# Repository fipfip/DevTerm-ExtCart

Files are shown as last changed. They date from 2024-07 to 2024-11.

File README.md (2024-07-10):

# DevTerm-ExtCart

An extension board for the DevTerm, with Commodore64-style 44pin cartridge.
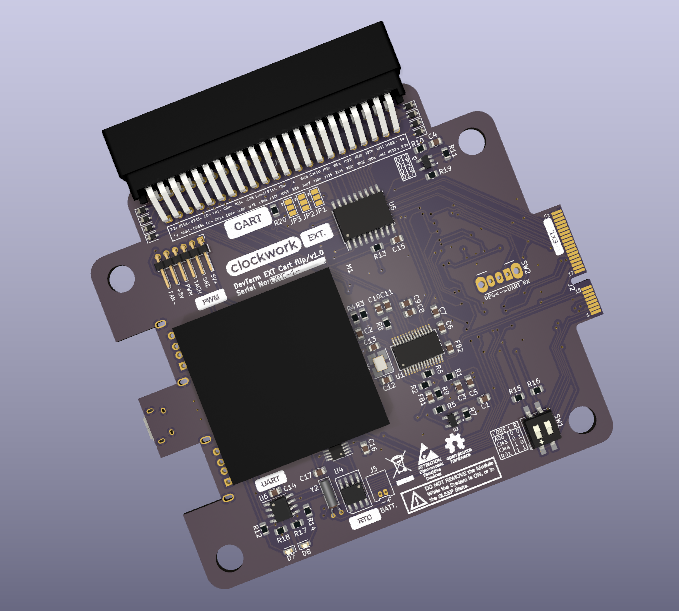
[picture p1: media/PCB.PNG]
PCB
 

## Design desiderata

Pin assignment:
- Maximum compatibility and function alignment.
- Strong coupling of differential pairs.
- Avoid damage.
All power pins are mirror safe.
Expansion port requirement:
- Pin 21 MUST connect to Pin 23.
- Pin 24 MUST be NC
ROUTE_EN disconnects all routed pins when cartridge is:
- Disconnected
- Inserted the wrong direction
Resource overview:
- 8x internal GPIOs
- 8x external GPIOs
- MIPI-CSI
- 3x USB 2.0
- 1x SPI
- 1x I2C
- 1x UART (Debug)
Resource management pins:
- IO36 for power management
- IO43 for cartridge detection

## PCB Physical specifications

- EXT board:
  - size: 89mm (height) x 101mm (width)
  - thickness: 1mm (source: https://www.ampltd.com/minipcie/)
- Carts:
  - size: 61mm (max height inside DevTerm) x 58.42mm (width)
  - thickness: 1.6mm (source: https://dirtypcbs.com/store/designer/details/12317/1036/cartridge-board-for-commodore-64)

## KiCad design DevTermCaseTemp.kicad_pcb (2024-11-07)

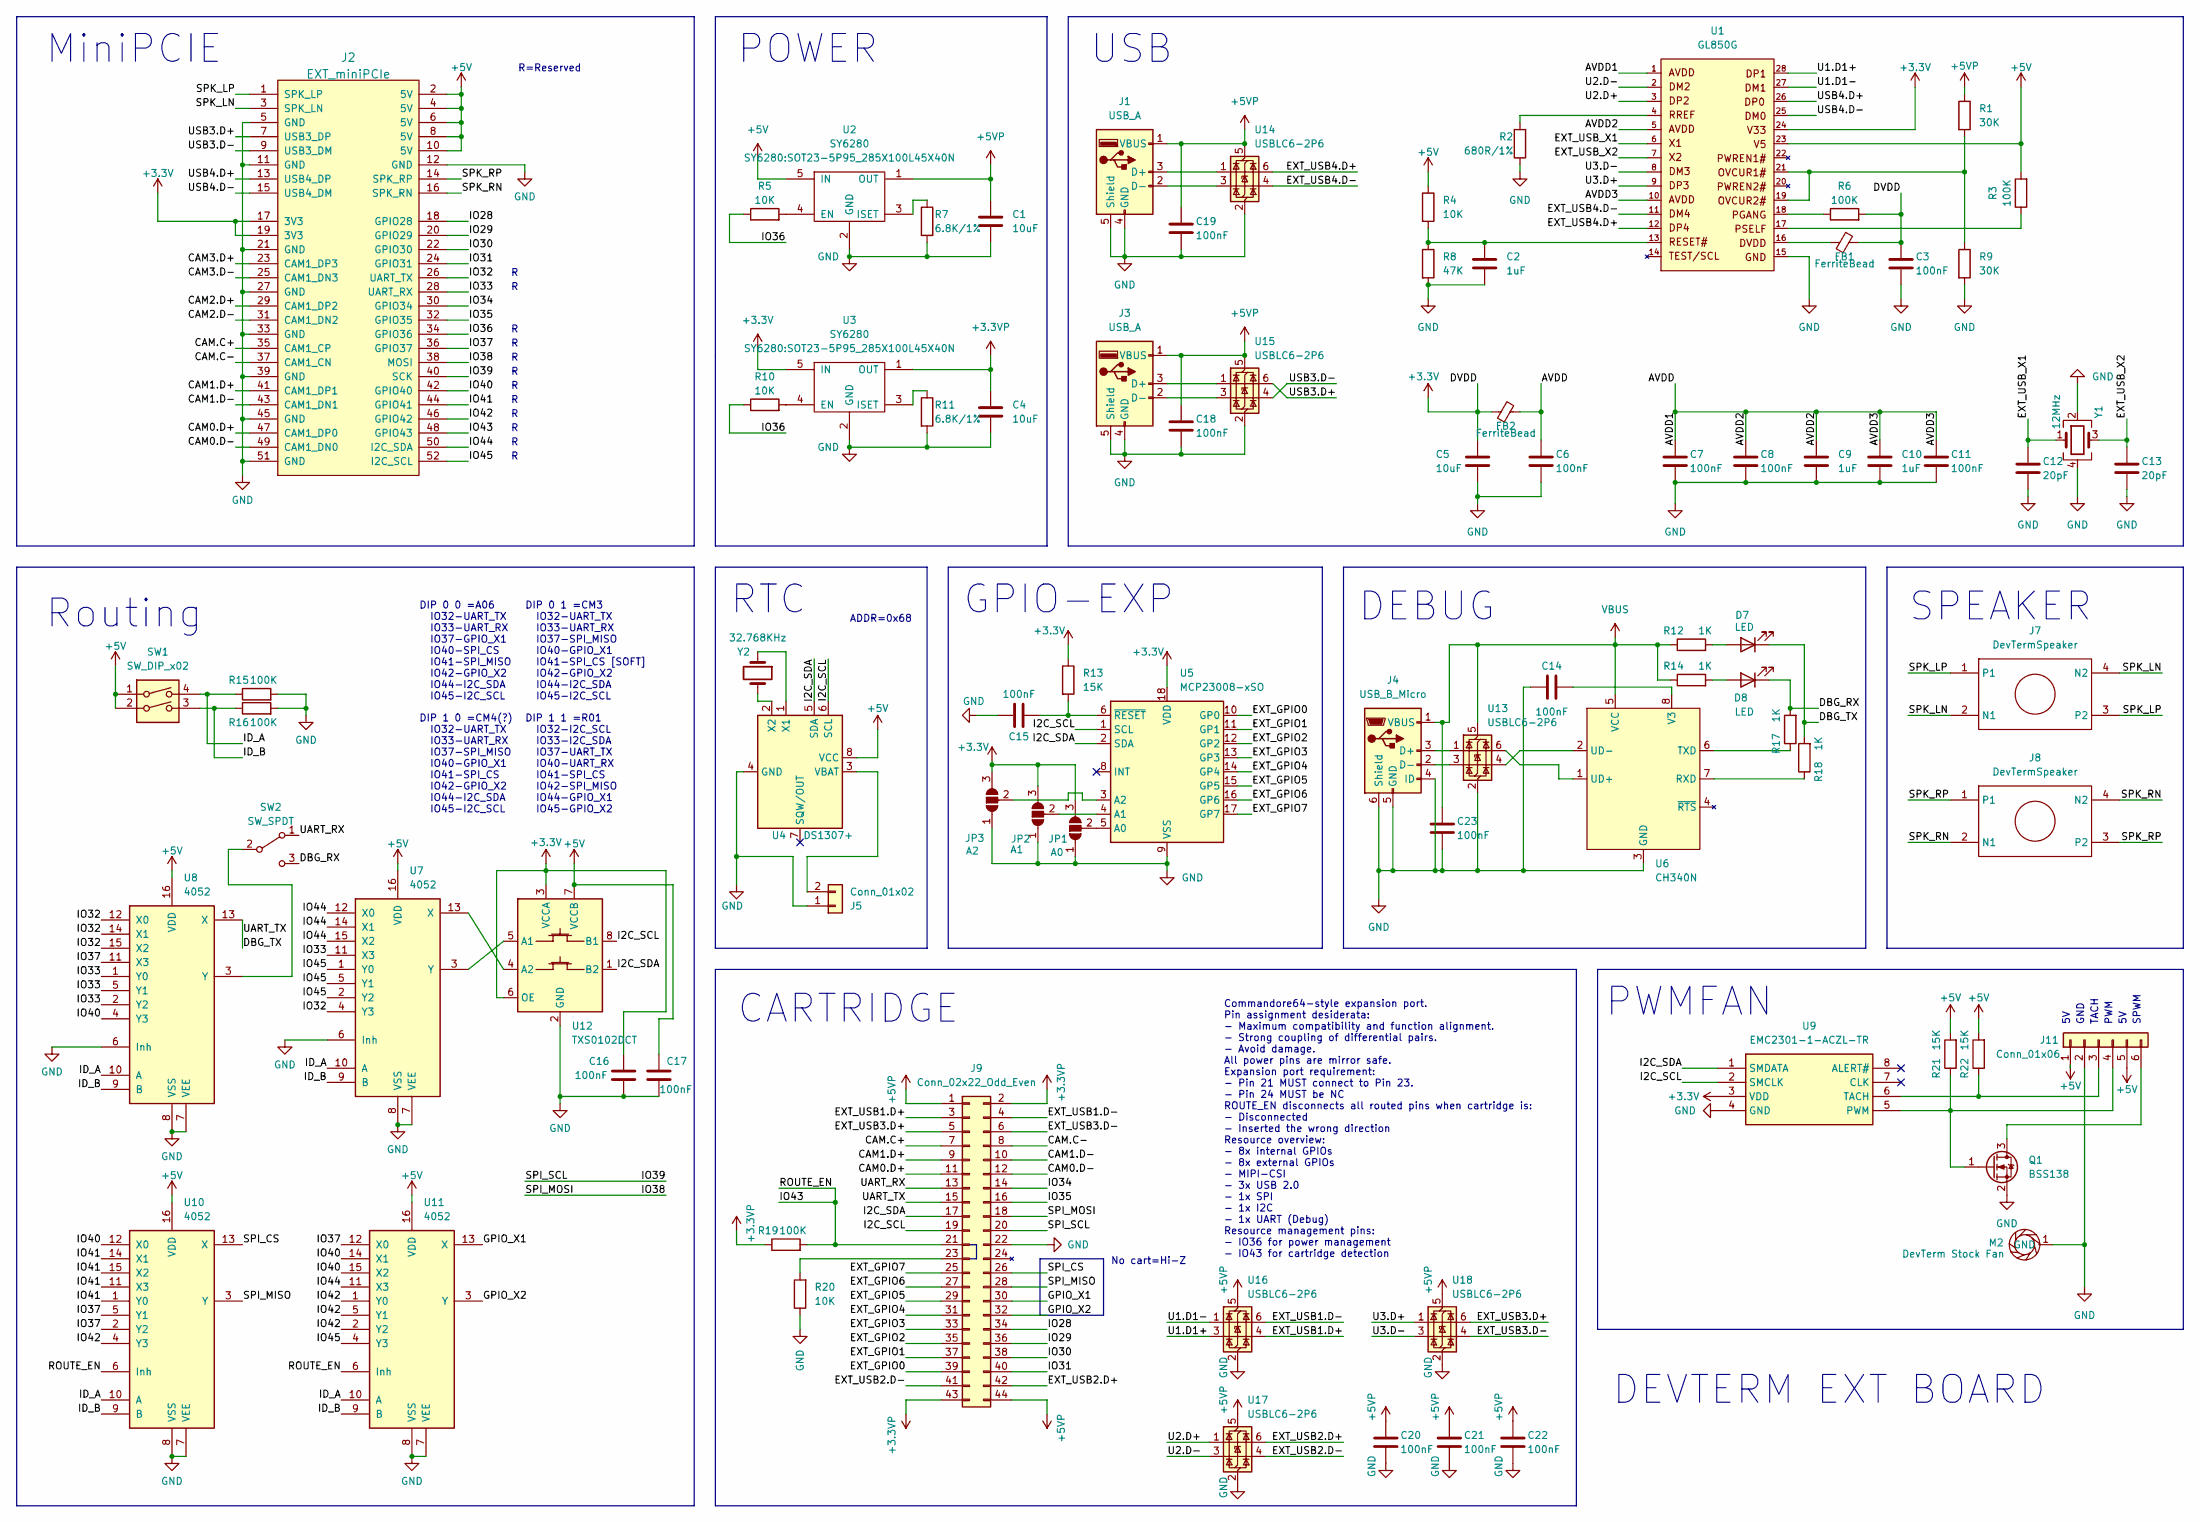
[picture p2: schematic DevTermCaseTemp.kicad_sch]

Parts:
C1, C4, C5: 10uF; C_0805_2012Metric
C2, C9, C10: 1uF; C_0805_2012Metric
C3, C6, C7, C8, C11, C14, C15, C16, C17, C18, C19, C20, C21, C22, C23: 100nF; C_0805_2012Metric
C12, C13: 20pF; C_0805_2012Metric
D7, D8: LED; LED_0603_1608Metric
FB1, FB2: FerriteBead; C_0805_2012Metric
J1, J3: USB_A; USB_A_PCBCUT
J2: EXT_miniPCIe; mini-PCIe
J4: USB_B_Micro; USB_Micro-B_Amphenol_10118194_Horizontal
J5: Conn_01x02; Molex_PicoBlade_53048-0210_1x02_P1.25mm_Horizontal
J7, J8: DevTermSpeaker; DevTerm-Speaker
J9: Conn_02x22_Odd_Even; C64-Cart-Socket-Horizontal
J11: Conn_01x06; PinHeader_1x06_P2.00mm_Horizontal
JP1: A0; SolderJumper-3_P1.3mm_Open_Pad1.0x1.5mm
JP2: A1; SolderJumper-3_P1.3mm_Open_Pad1.0x1.5mm
JP3: A2; SolderJumper-3_P1.3mm_Open_Pad1.0x1.5mm
M2: DevTerm Stock Fan; DevTerm-Stock-Fan
Q1: BSS138; SOT-23
R1, R9: 30K; R_0805_2012Metric
R2: 680R/1%; R_0805_2012Metric
R3, R6, R15, R16, R19: 100K; R_0805_2012Metric
R4, R5, R10, R20: 10K; R_0805_2012Metric
R7, R11: 6.8K/1%; R_0805_2012Metric
R8: 47K; R_0805_2012Metric
R12, R14, R17, R18: 1K; R_0805_2012Metric
R13, R21, R22: 15K; R_0805_2012Metric
SW1: SW_DIP_x02; SW_DIP_SPSTx02_Slide_6.7x6.64mm_W8.61mm_P2.54mm_LowProfile
SW2: SW_SPDT; SW_CuK_OS102011MA1QN1_SPDT_Angled
U1: GL850G; SSOP28
U2, U3: SY6280; SOT23-5P95_285X100L45X40N
U4: DS1307+; SOIC-8
U5: MCP23008-xSO; SOIC-18W_7.5x11.6mm_P1.27mm
U6: CH340N; SOP-8_3.9x4.9mm_P1.27mm
U7, U8, U10, U11: 4052; SOIC-16_3.9x9.9mm_P1.27mm
U9: EMC2301-1-ACZL-TR; SOP65P490X110-8N; Mouser Part Number 886-EMC2301-1-ACZLTR
U12: TXS0102DCT; MSOP-8_3x3mm_P0.65mm
U13, U14, U15, U16, U17, U18: USBLC6-2P6; SOT-666
Y1: 12MHz; Crystal_SMD_3225-4Pin_3.2x2.5mm_HandSoldering
Y2: 32.768KHz; Crystal_DS26_D2.0mm_L6.0mm_Horizontal

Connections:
+3.3V: C3.1, C5.1, C16.1, FB1.2, FB2.1, J2.17 (3V3), J2.19 (3V3), JP1.3 (B), JP2.3 (B), JP3.3 (B), R6.2, R13.1, U1.24, U3.5 (IN), U5.18 (VDD), U9.3 (VDD), U12.3 (VCCA), U12.6 (OE)
+3.3VP: C4.1, J9.2, J9.43, R19.1, U3.1 (OUT)
+5V: C17.1, J2.2 (5V), J2.4 (5V), J2.6 (5V), J2.8 (5V), J2.10 (5V), J11.1, J11.5, R3.2, R4.1, R21.2, R22.2, SW1.1, SW1.2, U1.23, U2.5 (IN), U4.8 (VCC), U7.16 (VDD), U8.16 (VDD), U10.16 (VDD), U11.16 (VDD), U12.7 (VCCB)
+5VP: C1.1, C18.1, C19.1, C20.1, C21.1, C22.1, J1.1 (VBUS), J3.1 (VBUS), J9.1, J9.44, R1.1, U2.1 (OUT), U14.5 (VBUS), U15.5 (VBUS), U16.5 (VBUS), U17.5 (VBUS), U18.5 (VBUS)
/AVDD: C6.1, C7.1, C8.1, C9.1, C10.1, C11.1, FB2.2, U1.1, U1.5, U1.10
/CAM0.D+: J2.47 (CAM1_DP0), J9.11
/CAM0.D-: J2.49 (CAM1_DN0), J9.12
/CAM1.D+: J2.41 (CAM1_DP1), J9.9
/CAM1.D-: J2.43 (CAM1_DN1), J9.10
/CAM2.D+: J2.29 (CAM1_DP2)
/CAM2.D-: J2.31 (CAM1_DN2)
/CAM3.D+: J2.23 (CAM1_DP3)
/CAM3.D-: J2.25 (CAM1_DN3)
/CAM.C+: J2.35 (CAM1_CP), J9.7
/CAM.C-: J2.37 (CAM1_CN), J9.8
/DBG_RX: D8.1 (K), R17.2, SW2.3 (C)
/DBG_TX: D7.1 (K), J9.15, R18.2, U8.13 (X)
/EXT_GPIO0: J9.39, U5.10 (GP0)
/EXT_GPIO1: J9.37, U5.11 (GP1)
/EXT_GPIO2: J9.35, U5.12 (GP2)
/EXT_GPIO3: J9.33, U5.13 (GP3)
/EXT_GPIO4: J9.31, U5.14 (GP4)
/EXT_GPIO5: J9.29, U5.15 (GP5)
/EXT_GPIO6: J9.27, U5.16 (GP6)
/EXT_GPIO7: J9.25, U5.17 (GP7)
/EXT_USB1.D+: J9.3, U16.4 (I/O2)
/EXT_USB1.D-: J9.4, U16.6 (I/O1)
/EXT_USB2.D+: J9.42, U17.6 (I/O1)
/EXT_USB2.D-: J9.41, U17.4 (I/O2)
/EXT_USB3.D+: J9.5, U18.6 (I/O1)
/EXT_USB3.D-: J9.6, U18.4 (I/O2)
/EXT_USB4.D+: U1.12, U14.6 (I/O1)
/EXT_USB4.D-: U1.11, U14.4 (I/O2)
/EXT_USB_X1: C12.1, U1.6, Y1.1
/EXT_USB_X2: C13.1, U1.7, Y1.3
/GPIO_X1: J9.30, U11.13 (X)
/GPIO_X2: J9.32, U11.3 (Y)
/I2C_SCL: J9.19, U4.6 (SCL), U5.1 (SCL), U9.2 (SMCLK), U12.8 (B1)
/I2C_SDA: J9.17, U4.5 (SDA), U5.2 (SDA), U9.1 (SMDATA), U12.1 (B2)
/ID_A: R15.1, SW1.4, U7.10 (A), U8.10 (A), U10.10 (A), U11.10 (A)
/ID_B: R16.1, SW1.3, U7.9 (B), U8.9 (B), U10.9 (B), U11.9 (B)
/IO28: J2.18 (GPIO28), J9.34
/IO29: J2.20 (GPIO29), J9.36
/IO30: J2.22 (GPIO30), J9.38
/IO31: J2.24 (GPIO31), J9.40
/IO32: J2.26 (UART_TX), U7.4 (Y3), U8.12 (X0), U8.14 (X1), U8.15 (X2)
/IO33: J2.28 (UART_RX), U7.11 (X3), U8.1 (Y0), U8.2 (Y2), U8.5 (Y1)
/IO34: J2.30 (GPIO34), J9.14
/IO35: J2.32 (GPIO35), J9.16
/IO36: J2.34 (GPIO36), R5.1, R10.1
/IO37: J2.36 (GPIO37), U8.11 (X3), U10.2 (Y2), U10.5 (Y1), U11.12 (X0)
/IO38: J2.38 (MOSI), J9.18
/IO39: J2.40 (SCK), J9.20
/IO40: J2.42 (GPIO40), U8.4 (Y3), U10.12 (X0), U11.14 (X1), U11.15 (X2)
/IO41: J2.44 (GPIO41), U10.1 (Y0), U10.11 (X3), U10.14 (X1), U10.15 (X2)
/IO42: J2.46 (GPIO42), U10.4 (Y3), U11.1 (Y0), U11.2 (Y2), U11.5 (Y1)
/IO43: J2.48 (GPIO43), J9.21, R19.2, U10.6 (Inh), U11.6 (Inh)
/IO44: J2.50 (I2C_SDA), U7.12 (X0), U7.14 (X1), U7.15 (X2), U11.11 (X3)
/IO45: J2.52 (I2C_SCL), U7.1 (Y0), U7.2 (Y2), U7.5 (Y1), U11.4 (Y3)
/SPI_CS: J9.26, U10.13 (X)
/SPI_MISO: J9.28, U10.3 (Y)
/SPK_LN: J2.3 (SPK_LN), J7.2 (N1), J7.4 (N2)
/SPK_LP: J2.1 (SPK_LP), J7.1, J7.3 (P2)
/SPK_RN: J2.16 (SPK_RN), J8.2 (N1), J8.4 (N2)
/SPK_RP: J2.14 (SPK_RP), J8.1, J8.3 (P2)
/U1.D1+: U1.28, U16.3 (I/O2)
/U1.D1-: U1.27, U16.1 (I/O1)
/U2.D+: U1.3, U17.1 (I/O1)
/U2.D-: U1.2, U17.3 (I/O2)
/U3.D+: U1.9, U18.1 (I/O1)
/U3.D-: U1.8, U18.3 (I/O2)
/UART_RX: J9.13, SW2.1 (A)
/USB3.D+: J2.7 (USB3_DP), U15.6 (I/O1)
/USB3.D-: J2.9 (USB3_DM), U15.4 (I/O2)
/USB4.D+: J2.13 (USB4_DP), U1.26
/USB4.D-: J2.15 (USB4_DM), U1.25
GND: C1.2, C2.2, C3.2, C4.2, C5.2, C6.2, C7.2, C8.2, C9.2, C10.2, C11.2, C12.2, C13.2, C14.2, C15.1, C16.2, C17.2, C18.2, C19.2, C20.2, C21.2, C22.2, C23.2, J1.4 (GND), J1.5 (Shield), J2.5 (GND), J2.11 (GND), J2.12 (GND), J2.21 (GND), J2.27 (GND), J2.33 (GND), J2.39 (GND), J2.45 (GND), J2.51 (GND), J3.4 (GND), J3.5 (Shield), J4.4 (ID), J4.5 (GND), J4.6 (Shield), J5.1, J9.22, J11.2, JP1.1 (A), JP2.1 (A), JP3.1 (A), M2.1 (GND), Q1.2 (S), R2.1, R7.2, R8.2, R9.2, R11.2, R15.2, R16.2, R20.1, U1.15, U2.2 (GND), U3.2 (GND), U4.4 (GND), U5.9 (VSS), U6.3 (GND), U7.6 (Inh), U7.7 (VEE), U7.8 (VSS), U8.6 (Inh), U8.7 (VEE), U8.8 (VSS), U9.4 (GND), U10.7 (VEE), U10.8 (VSS), U11.7 (VEE), U11.8 (VSS), U12.2 (GND), U13.2 (GND), U14.2 (GND), U15.2 (GND), U16.2 (GND), U17.2 (GND), U18.2 (GND), Y1.2, Y1.4
unnamed: C2.1, R4.2, R8.1, U1.13
unnamed: D7.2 (A), R12.2
unnamed: D8.2 (A), R14.2
unnamed: FB1.1, U1.16
unnamed: J1.3 (D+), U14.1 (I/O1)
unnamed: J1.2 (D-), U14.3 (I/O2)
unnamed: J3.3 (D+), U15.1 (I/O1)
unnamed: J3.2 (D-), U15.3 (I/O2)
unnamed: J4.3 (D+), U13.1 (I/O1)
unnamed: J4.2 (D-), U13.3 (I/O2)
unnamed: J5.2, U4.3 (VBAT)
unnamed: J9.23, R20.2
unnamed: J11.3, R22.1, U9.6 (TACH)
unnamed: J11.4, Q1.1 (G), R21.1, U9.5 (PWM)
unnamed: J11.6, Q1.3 (D)
unnamed: JP1.2 (C), U5.5 (A0)
unnamed: JP2.2 (C), U5.4 (A1)
unnamed: JP3.2 (C), U5.3 (A2)
unnamed: R1.2, R9.1, U1.19, U1.21
unnamed: R2.2, U1.4
unnamed: R3.1, U1.17
unnamed: R6.1, U1.18
unnamed: SW2.2 (B), U8.3 (Y)
unnamed: R5.2, U2.4 (EN)
unnamed: R7.1, U2.3 (ISET)
unnamed: R10.2, U3.4 (EN)
unnamed: R11.1, U3.3 (ISET)
unnamed: U4.1 (X1), Y2.1
unnamed: U4.2 (X2), Y2.2
unnamed: C15.2, R13.2, U5.6 (~RESET)
unnamed: R18.1, U6.7 (RXD)
unnamed: R17.1, U6.6 (TXD)
unnamed: U6.1 (UD+), U13.6 (I/O1)
unnamed: U6.2 (UD-), U13.4 (I/O2)
unnamed: C14.1, U6.8 (V3)
unnamed: U7.3 (Y), U12.5 (A1)
unnamed: U7.13 (X), U12.4 (A2)
VBUS: C23.1, J4.1 (VBUS), R12.1, R14.1, U6.5 (VCC), U13.5 (VBUS)

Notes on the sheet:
CARTRIDGE
Commandore64-style expansion port. Pin assignment desiderata: - Maximum compatibility and function alignment. - Strong coupling of differential pairs. - Avoid damage. All power pins are mirror safe. Expansion port requirement: - Pin 21 MUST connect to Pin 23. - Pin 24 MUST be NC ROUTE_EN disconnect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
DIP 0 0 =A06 IO32-UART_TX IO33-UART_RX IO37-GPIO_X1 IO40-SPI_CS IO41-SPI_MISO IO42-GPIO_X2 IO44-I2C_SDA IO45-I2C_SCL
GPIO-EXP
MiniPCIE
USB
R=Reserved
DIP 0 1 =CM3 IO32-UART_TX IO33-UART_RX IO37-SPI_MISO IO40-GPIO_X1 IO41-SPI_CS [SOFT] IO42-GPIO_X2 IO44-I2C_SDA IO45-I2C_SCL
DEVTERM EXT BOARD
GND
POWER
ADDR=0x68
TACH
PWMFAN
DEBUG
PWM
Routing
SPWM
SPEAKER
No cart=Hi-Z
DIP 1 1 =R01 IO32-I2C_SCL IO33-I2C_SDA IO37-UART_TX IO40-UART_RX IO41-SPI_CS IO42-SPI_MISO IO44-GPIO_X1 IO45-GPIO_X2
DIP 1 0 =CM4(?) IO32-UART_TX IO33-UART_RX IO37-SPI_MISO IO40-GPIO_X1 IO41-SPI_CS IO42-GPIO_X2 IO44-I2C_SDA IO45-I2C_SCL
RTC

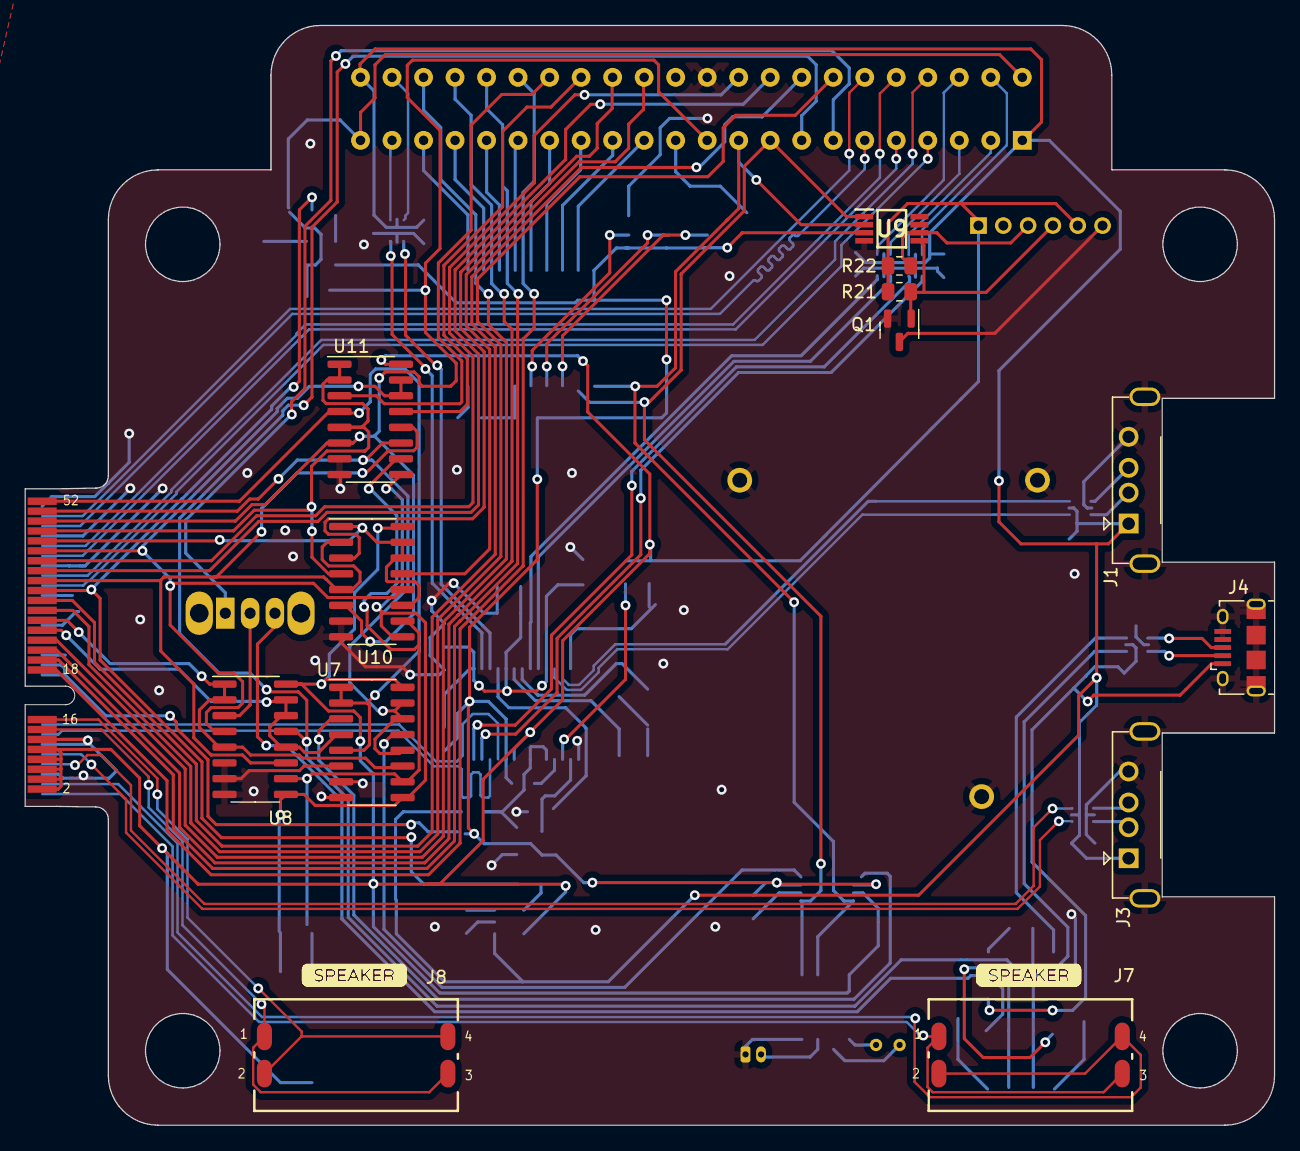
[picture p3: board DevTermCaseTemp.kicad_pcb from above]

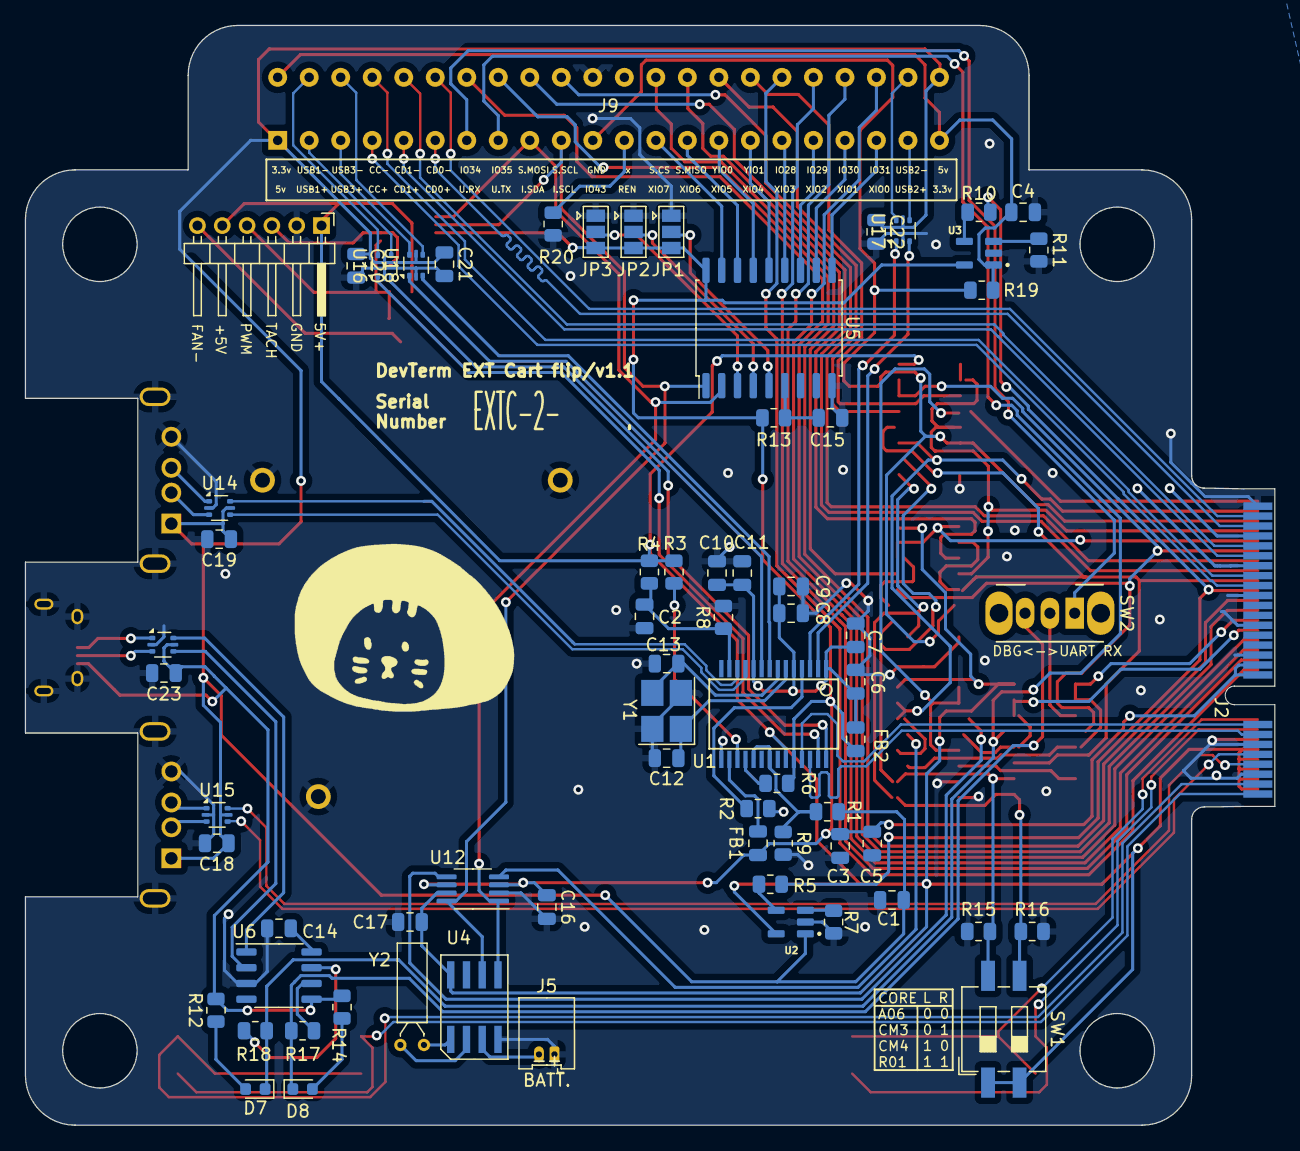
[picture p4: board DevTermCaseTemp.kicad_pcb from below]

Board: 2 copper layers, 100.7 x 88.6 mm, 85 parts (72 on the bottom side), 111 nets.

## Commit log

2023-01-16 in production. good luck!
    [DevTermCaseTemp.kicad_pcb, DevTermCaseTemp.kicad_sch, DevTermCaseTemp_bad.kicad_pcb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]
2023-01-23 i2c level shifter to ssop
    [DevTermCaseTemp.kicad_pcb, DevTermCaseTemp.kicad_sch]
2023-02-07 v3 is finalized
    [DevTermCaseTemp.kicad_sch]
2023-02-08 add uart rx switch
2023-02-17 turbo fan is now a component
    [DevTermCaseTemp_v4.kicad_sch]
2023-02-17 add BOM table
    [DevTermCaseTemp_v4.csv]
2023-02-17 add ROUTE_EN pull down resistor
    [DevTermCaseTemp_v4.kicad_sch]
2023-02-28 add printer cart submodule
2023-04-01 Add R20 to BOM
2023-04-05 update B.Silkscreen to annotate RTC batt and DBG/UART RX switch
    [DevTermCaseTemp_v4.csv]
2023-04-05 after adding R20, Pin 23 is not GND any more. Annotate as REN.
2023-08-14 File cleanup
    Moved library files into /lib/ directory, moved media in /media/ folder
    [DevTermCaseTemp.kicad_sch, DevTermCaseTemp_v4.csv, DevTermCaseTemp_v4.kicad_sch]
2024-07-10 Schematic: - Replace GP7101 with EMC2301 and add support for directly driven fan - Replace 3505/3507 fan with either a CUI Devices CBM-35CF or stock DevTerm fan - Use correct footprint for MCP23008
    Board:
    - Overhaul MIPI CSI line to match impedance and enhance EMC
    - Route new fan component
    [DevTermCaseTemp.kicad_sch]
2024-07-10 Fix supply of EMC2301, add serial number field
    [DevTermCaseTemp.kicad_sch]
2024-07-10 Final error correction and DRC
    - fixed minor silkscreen mistakes
    - added 3D models of fan and C64 connector
    - Updated README.md
    [DevTermCaseTemp.kicad_sch]
2024-11-06 Replaced ESD surge diodes with USBLC6
    [DevTermCaseTemp.kicad_sch]
2024-11-07 Added bypass caps for USB ESD surge protection as specified in datasheet.
    + Updated silkscreen for version and serial number
    [DevTermCaseTemp.kicad_pcb, DevTermCaseTemp.kicad_sch]
